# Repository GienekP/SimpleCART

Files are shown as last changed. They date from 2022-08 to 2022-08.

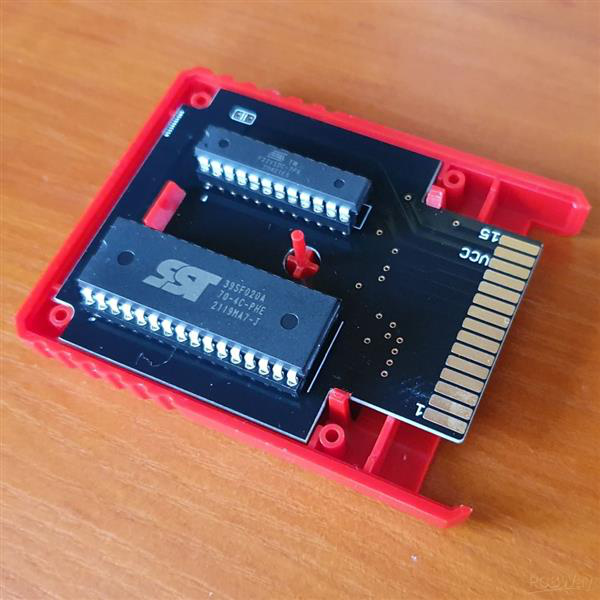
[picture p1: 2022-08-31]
SimpleCART.jpg

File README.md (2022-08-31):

# SimpleCART
Cartridge project for ATARI XE computers based on ATF22V10C

This bank-switched cartridge occupies 8 KB of address space between $A000 and $BFFF. The cartridge memory is divided into 16 banks, 8 KB each. The 4 lowest bits of the DATA written to $D500-$D50F (mirrored) select the bank mapped to $A000-$BFFF. Writing to $D510-$D51F disables the cartridge. The 2 lowest bits of the DATA written to $D520-$D52F (mirrored) select the "side" of SST39SF020A/SST39SF040"

SST39SF010A - 128kB

SST39SF020A - 256kB (2 sides)

SST39SF040 - 512kB (4 sides)

E.g.

POKE 54528,5 - select bank: 5

POKE 54560,1 - select side: 1

POKE 54544,0 - disable CART

The presented solution can be used unlimitedly and freely without any legal obligations, especially in the field of educational, commercial and non-commercial activities.

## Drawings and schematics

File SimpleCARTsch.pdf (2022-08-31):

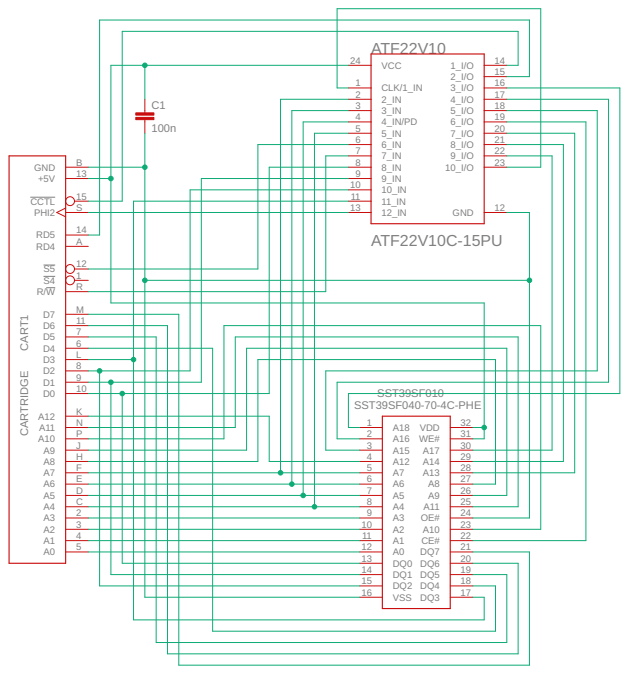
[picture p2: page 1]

CARTRIDGE SST39SF040-70-4C-PHE 100n CCTL 15 S4 1 S5 12 +5V 13 A0 5 A1 4 A2 3 A3 2 A4 C A5 D A6 E A7 F A8 H A9 J A10 P A11 N A12 K D0 10 D1 9 D2 8 D3 L D4 6 D5 7 D6 11 D7 M GND B PHI2 S R/W R RD4 A RD5 14 CART1 A18 1 A16 2 A15 3 A12 4 A7 5 A6 6 A5 7 A4 8 A3 9 A2 10 A1 11 A0 12 DQ0 13 DQ1 14 DQ2 15 VSS 16 VDD 32 WE# 31 A17 30 A14 29 A13 28 A8 27 A9 26 A11 25 OE# 24 A10 23 CE# 22 DQ7 21 DQ6 20 DQ5 19 DQ4 18 DQ3 17 SST39SF010 ATF22V10C-15PU VCC 24 2_IN 2 3_IN 3 5_IN 5 6_IN 6 7_IN 7 8_IN 8 9_IN 9 10_IN 10 11_IN 11 12_IN 13 4_IN/PD 4 CLK/1_IN 1 1_I/O 14 2_I/O 15 3_I/O 16 4_I/O 17 5_I/O 18 6_I/O 19 7_I/O 20 8_I/O 21 9_I/O 22 10_I/O 23 GND 12 ATF22V10 C1

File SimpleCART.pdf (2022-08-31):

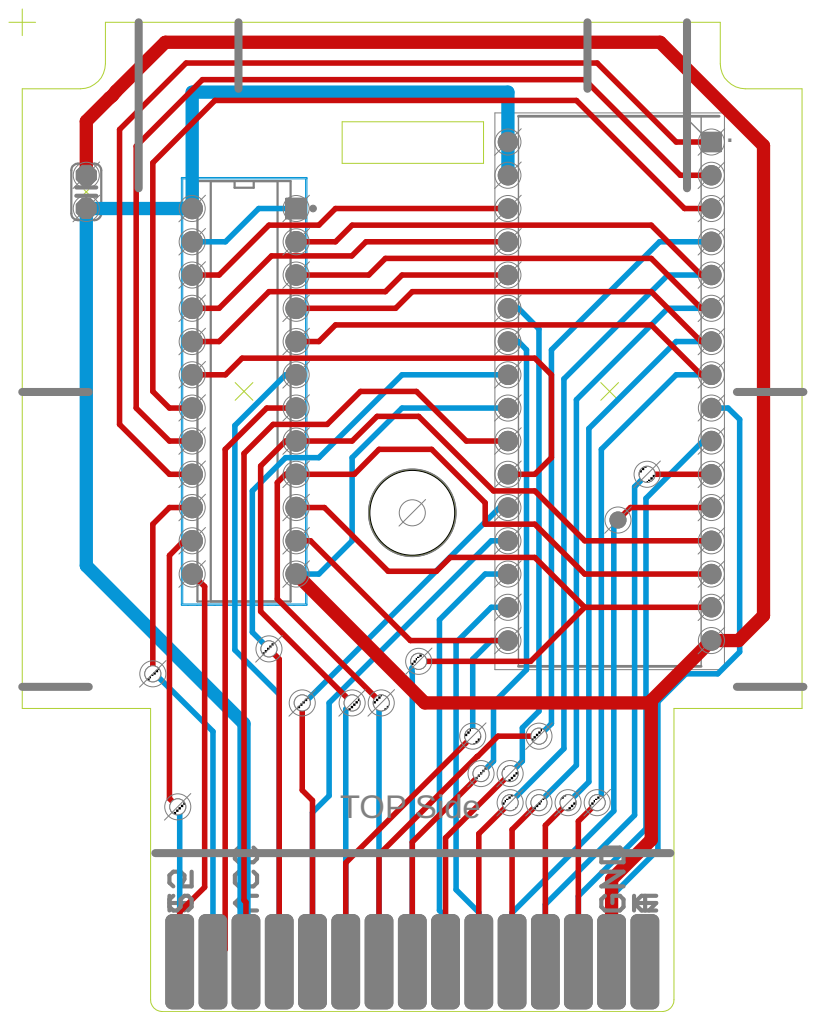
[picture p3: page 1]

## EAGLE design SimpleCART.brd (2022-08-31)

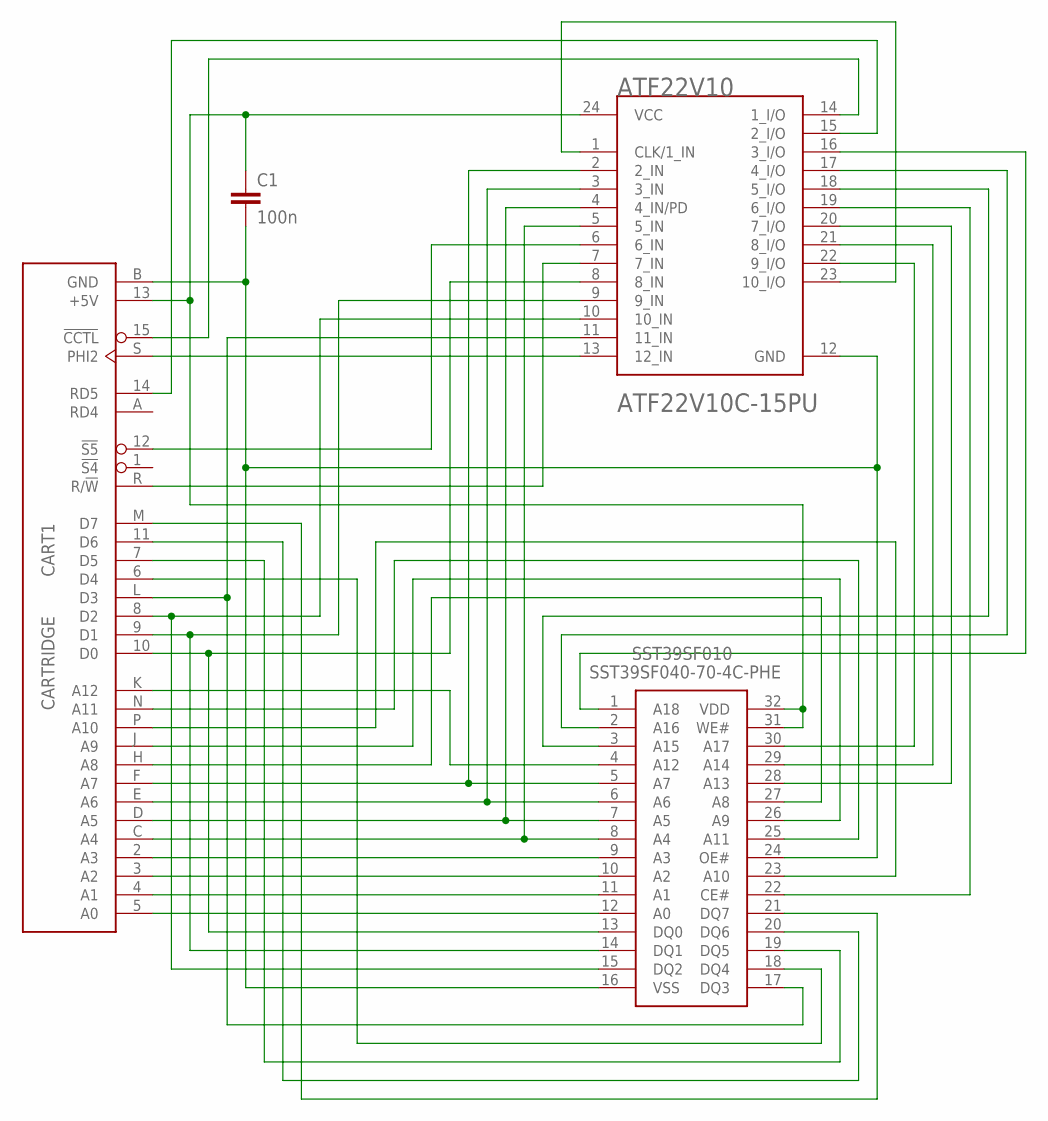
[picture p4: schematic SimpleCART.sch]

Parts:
ATF22V10: MICROCHIP_ATF22V10C-15PUMICROCHIP_ATF22V10C-15PU_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; MICROCHIP_ATF22V10C-15PU_0
C1: 100n; C025-024X044
CART1: CARTRIDGE
SST39SF010: SST39SF040-70-4C-PHE; DIP1556W56P254L4191H508Q32N

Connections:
A0: CART1.5 (A0), SST39SF010.12 (A0)
A1: CART1.4 (A1), SST39SF010.11 (A1)
A2: CART1.3 (A2), SST39SF010.10 (A2)
A3: CART1.2 (A3), SST39SF010.9 (A3)
A4: ATF22V10.5 (5_IN), CART1.C (A4), SST39SF010.8 (A4)
A5: ATF22V10.4 (4_IN/PD), CART1.D (A5), SST39SF010.7 (A5)
A6: ATF22V10.3 (3_IN), CART1.E (A6), SST39SF010.6 (A6)
A7: ATF22V10.2 (2_IN), CART1.F (A7), SST39SF010.5 (A7)
A8: CART1.H (A8), SST39SF010.27 (A8)
A9: CART1.J (A9), SST39SF010.26 (A9)
A10: CART1.P (A10), SST39SF010.23 (A10)
A11: CART1.N (A11), SST39SF010.25 (A11)
A12: CART1.K (A12), SST39SF010.4 (A12)
A13: ATF22V10.20 (7_I/O), SST39SF010.28 (A13)
A14: ATF22V10.21 (8_I/O), SST39SF010.29 (A14)
A15: ATF22V10.18 (5_I/O), SST39SF010.3 (A15)
A16: ATF22V10.17 (4_I/O), SST39SF010.2 (A16)
A17: ATF22V10.22 (9_I/O), SST39SF010.30 (A17)
A18: ATF22V10.16 (3_I/O), SST39SF010.1 (A18)
CCTL: ATF22V10.14 (1_I/O), CART1.15 (!CCTL)
CE: ATF22V10.19 (6_I/O), SST39SF010.22 (CE#)
CLK: ATF22V10.1 (CLK/1_IN), ATF22V10.23 (10_I/O)
D0: ATF22V10.8 (8_IN), CART1.10 (D0), SST39SF010.13 (DQ0)
D1: ATF22V10.9 (9_IN), CART1.9 (D1), SST39SF010.14 (DQ1)
D2: ATF22V10.10 (10_IN), CART1.8 (D2), SST39SF010.15 (DQ2)
D3: ATF22V10.11 (11_IN), CART1.L (D3), SST39SF010.17 (DQ3)
D4: CART1.6 (D4), SST39SF010.18 (DQ4)
D5: CART1.7 (D5), SST39SF010.19 (DQ5)
D6: CART1.11 (D6), SST39SF010.20 (DQ6)
D7: CART1.M (D7), SST39SF010.21 (DQ7)
GND: ATF22V10.12 (GND), C1.2, CART1.B (GND), SST39SF010.16 (VSS), SST39SF010.24 (OE#)
PHI2: ATF22V10.13 (12_IN), CART1.S (PHI2)
RD5: ATF22V10.15 (2_I/O), CART1.14 (RD5)
RW: ATF22V10.7 (7_IN), CART1.R (R/!W)
S5: ATF22V10.6 (6_IN), CART1.12 (!S5)
VCC: ATF22V10.24 (VCC), C1.1, CART1.13 (+5V), SST39SF010.31 (WE#), SST39SF010.32 (VDD)

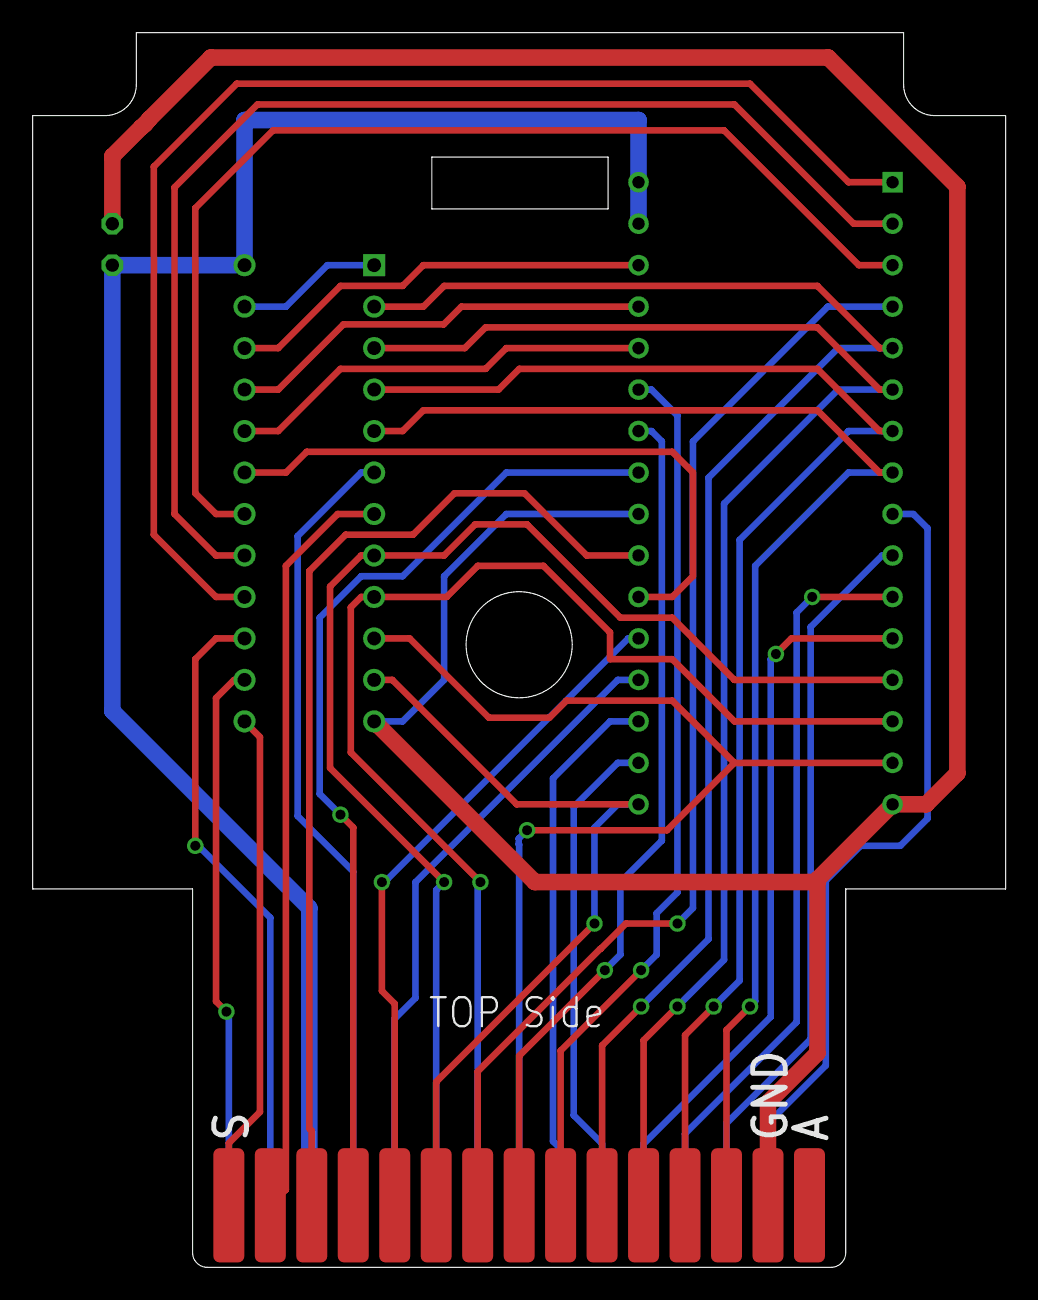
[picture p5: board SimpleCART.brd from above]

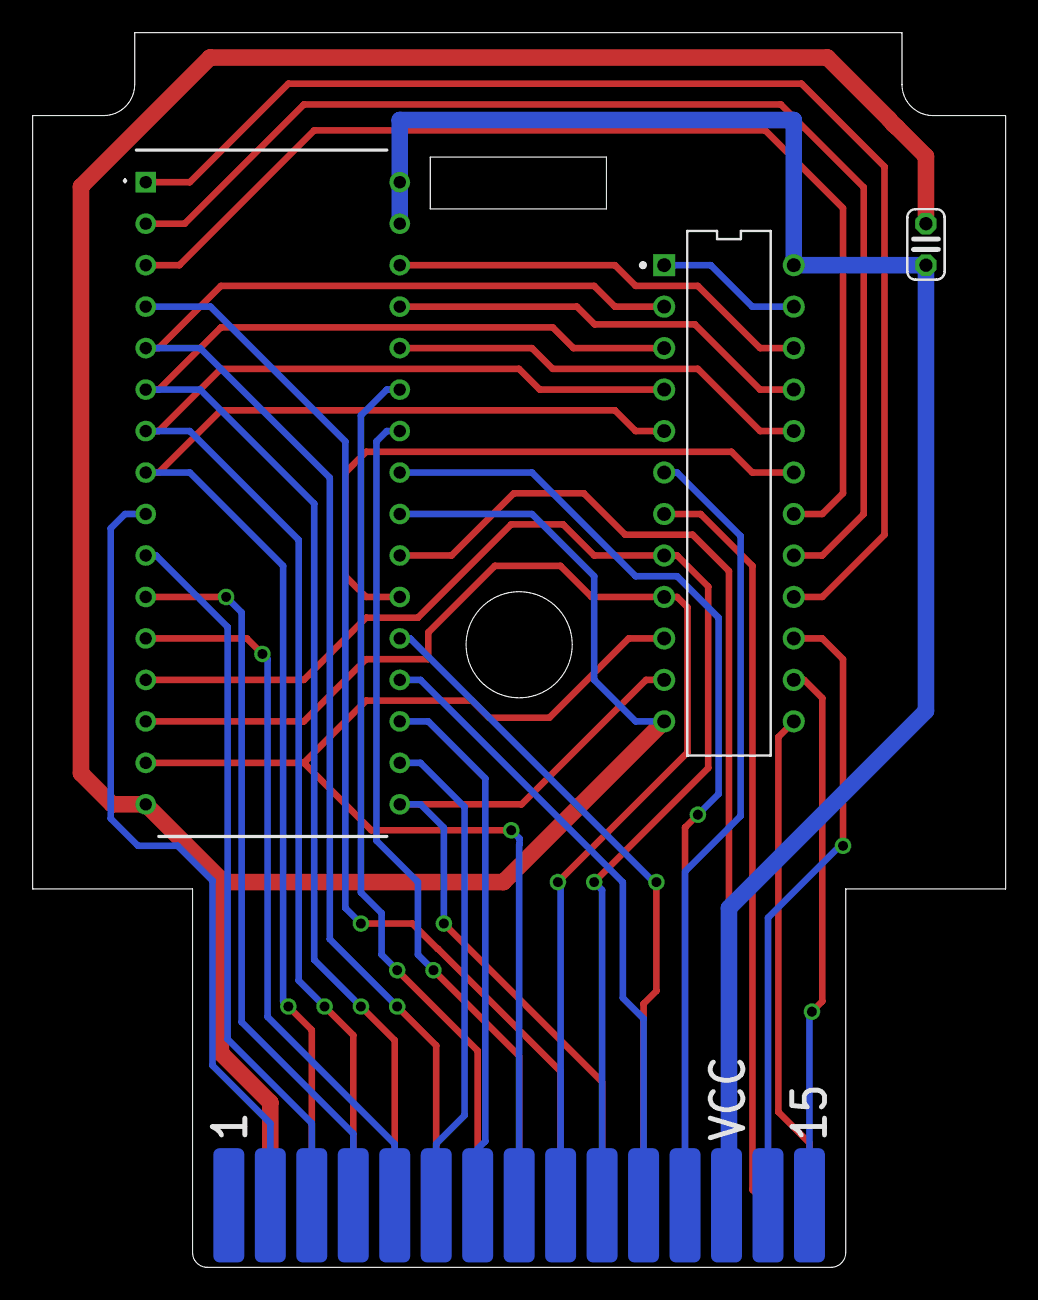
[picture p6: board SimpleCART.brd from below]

Board: 2 copper layers, 59.6 x 75.6 mm, 4 parts (4 on the bottom side), 36 nets.
